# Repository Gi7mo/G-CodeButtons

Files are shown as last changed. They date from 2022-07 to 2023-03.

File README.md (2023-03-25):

**G-Code Button PCB for [Agent Cain's Gcode Buttons](https://github.com/Agent-Cain/VoronUsers/tree/Voron-2_RGB_G-Code_Button/printer_mods/Agent-Cain/rgb_gcode-button)**

**BOM**
|Part NO.  |Qty  |LCSC  |Ali|
|--|--|--|--|
| Conn_01x03 | 1 | C131339 |[Link](https://s.click.aliexpress.com/e/_DlHystD)|
| Conn_01x04 | 1 | C131334 |[Link](https://s.click.aliexpress.com/e/_DlHystD)|
| WS2812-5050 | 1 | C114586 |[Link](https://s.click.aliexpress.com/e/_DCDujNX)|
| ROMER_G | 1 | --- |[Link](https://s.click.aliexpress.com/e/_DEeJCu3)|

**Assembly**
- Order the pcb at e.g. [pcbway](https://www.pcbway.com/project/shareproject/G_Code_Button_PCB_for_Agent_Cain_s_Gcode_Buttons_28c76498.html) or [jlcpcb](https://jlcpcb.com/)
- Order the buttons at e.g. [aliexpress](https://s.click.aliexpress.com/e/_DEeJCu3)
- Order the PH connectors at e.g. [aliexpress](https://s.click.aliexpress.com/e/_DdgpLUT)
- Assemble the PCB, the led is solderable by hand with a fine tip
- Wire up the pcbs to your controller
    - You can wire multiple pcb's in series, just go from data out (DO) to data in (DI) and expose only the switch (SW) cable for every pcb to your controller
- Add them as gcode buttons to your config
```
[gcode_button _EMERGENCY]
pin: ^!PE8
press_gcode:
    M112
```

- if you wan't e.g. a color change during press and macro execution, you can do it like this
```
[gcode_button _FILAMENT_UNLOAD]
pin: ^!PC12
press_gcode:
    SET_LED LED=buttons RED=1 GREEN=0 BLUE=0 index=2
    FILAMENT_UNLOAD
    SET_LED LED=buttons RED=1 GREEN=0.5 BLUE=0 index=2
```
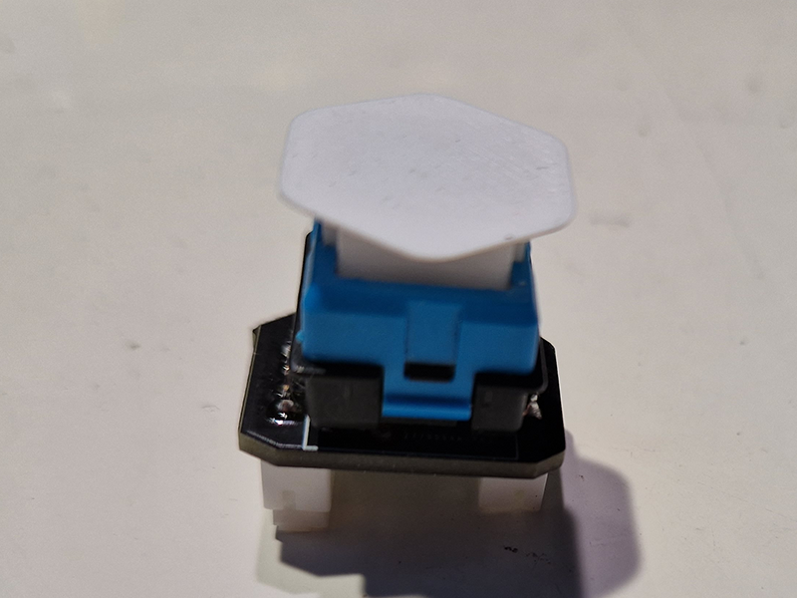
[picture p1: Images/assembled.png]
assembled
- 
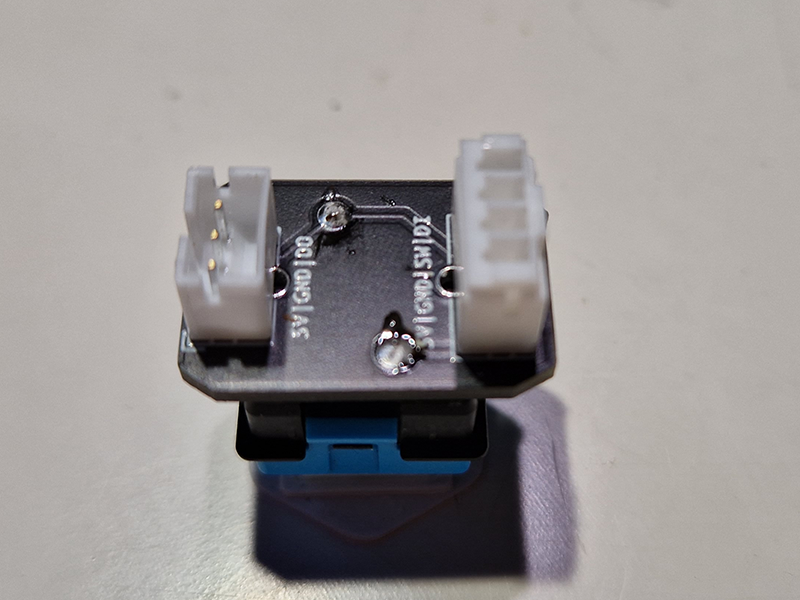
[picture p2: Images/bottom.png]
bottom
- 
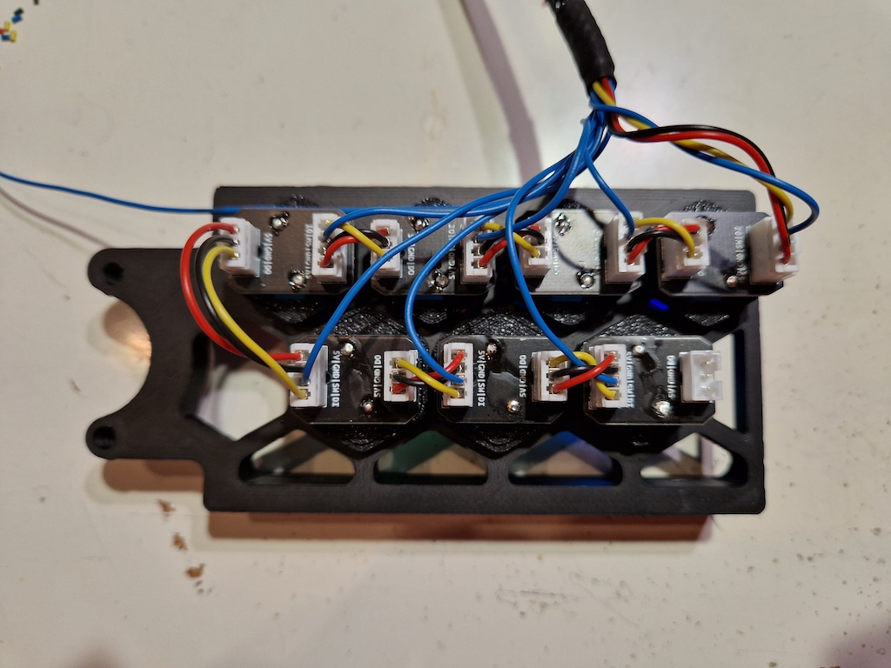
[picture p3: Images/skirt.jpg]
skirt
- 

## Troubleshooting
- Problem: My Leds showing Random colors
    - Solution: Add a ~400Ω Resistor on the data line

## Notes
- You can contact me via Discord "Gi7mo!#4618"
- This readme file contains Amazon Associate, Aliexpress affiliate, PCBWay affiliate links. I make a comission on qualifying purchases.
- This project does not come with any warranty, if you choose to build/use one, you are doing this at your own risk!

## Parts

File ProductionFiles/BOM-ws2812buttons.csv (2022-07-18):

Comment | Designator | Footprint | LCSC
Conn_01x03_Male | J2 | JST_PH_B3B-PH-K_1x03_P2.00mm_Vertical
Conn_01x04_Male | J1 | JST_PH_B4B-PH-K_1x04_P2.00mm_Vertical
WS2812B | D1 | LED_WS2812B_PLCC4_5.0x5.0mm_P3.2mm
B3K-T13L | U1 | Omron B3K-T13L

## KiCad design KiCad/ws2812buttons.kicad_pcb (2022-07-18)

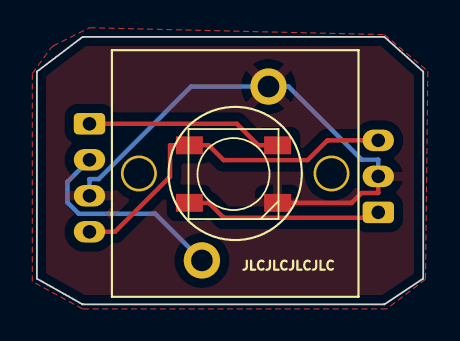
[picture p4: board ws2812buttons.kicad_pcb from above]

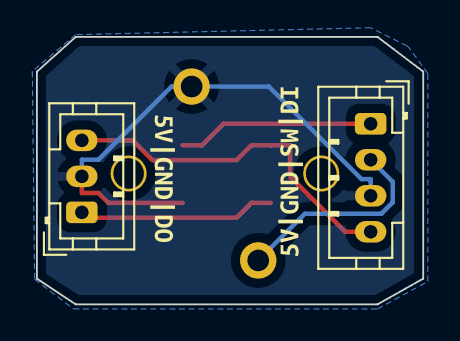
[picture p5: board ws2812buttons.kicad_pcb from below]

Board: 2 copper layers, 21.5 x 14.9 mm, 6 parts (4 on the bottom side), 5 nets.

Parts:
D1: WS2812B; LED_WS2812B_PLCC4_5.0x5.0mm_P3.2mm
J1: Conn_01x04_Male; JST_PH_B4B-PH-K_1x04_P2.00mm_Vertical
J2: Conn_01x03_Male; JST_PH_B3B-PH-K_1x03_P2.00mm_Vertical
U1: B3K-T13L; Omron B3K-T13L
kibuzzard-62A4DD9F: G***; kibuzzard-62A4DD9F
kibuzzard-62B786EE: G***; kibuzzard-62B786EE

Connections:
+5V: D1.1 (VDD), J1.4, J2.3
/DIN: D1.4 (DIN), J1.1
/DOUT: D1.2 (DOUT), J2.1
GND: D1.3 (VSS), J1.3, J2.2, U1.1
unnamed: J1.2, U1.2

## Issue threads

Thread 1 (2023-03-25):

LED

Dragi2k, 2023-03-25:
in your BOM it said WS2812 2020 but it is a 5050

Gi7mo, 2023-03-25:
thx for the hint

Dragi2k, 2023-03-25:
yea i bought the wrong one :-D

Gi7mo, 2023-03-25:
i'm very sorry for that

Closed 2023-03-25.
